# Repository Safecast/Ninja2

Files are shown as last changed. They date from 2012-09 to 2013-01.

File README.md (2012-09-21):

### Ninja2

Ninja2 is a board providing USB enabled atmega32u4 chip as the brain with an
802.15.4 radio for communication. It has a Li-Poly battery charger for juice
with a flexible booster that offers 3.3V to the microcontroller.

It can accomodate an OLED display from adafruit industries, a 13mm buzzer and a tactile switch for input.
http://www.adafruit.com/products/326

It was designed specifically for SAFECAST Japan as a complement to the bGeigie.

The board is cut to fit in Takachi box TW / TWN5-4-7.

The microcontroller will use the Arduino Leonardo bootloader and the Freaklabs chibiArduino 802.15.4 stack.

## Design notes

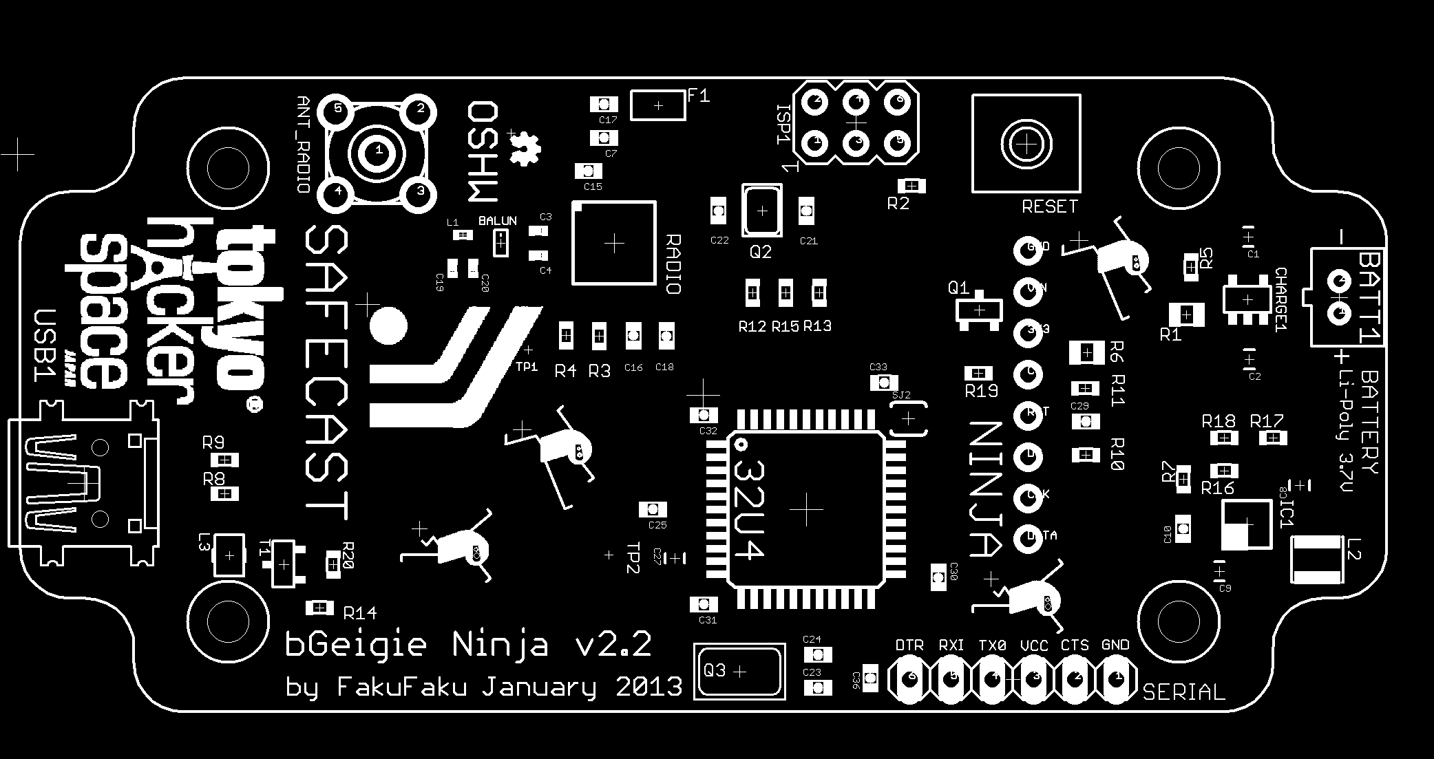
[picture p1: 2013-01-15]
Ninja2_brdtop.png

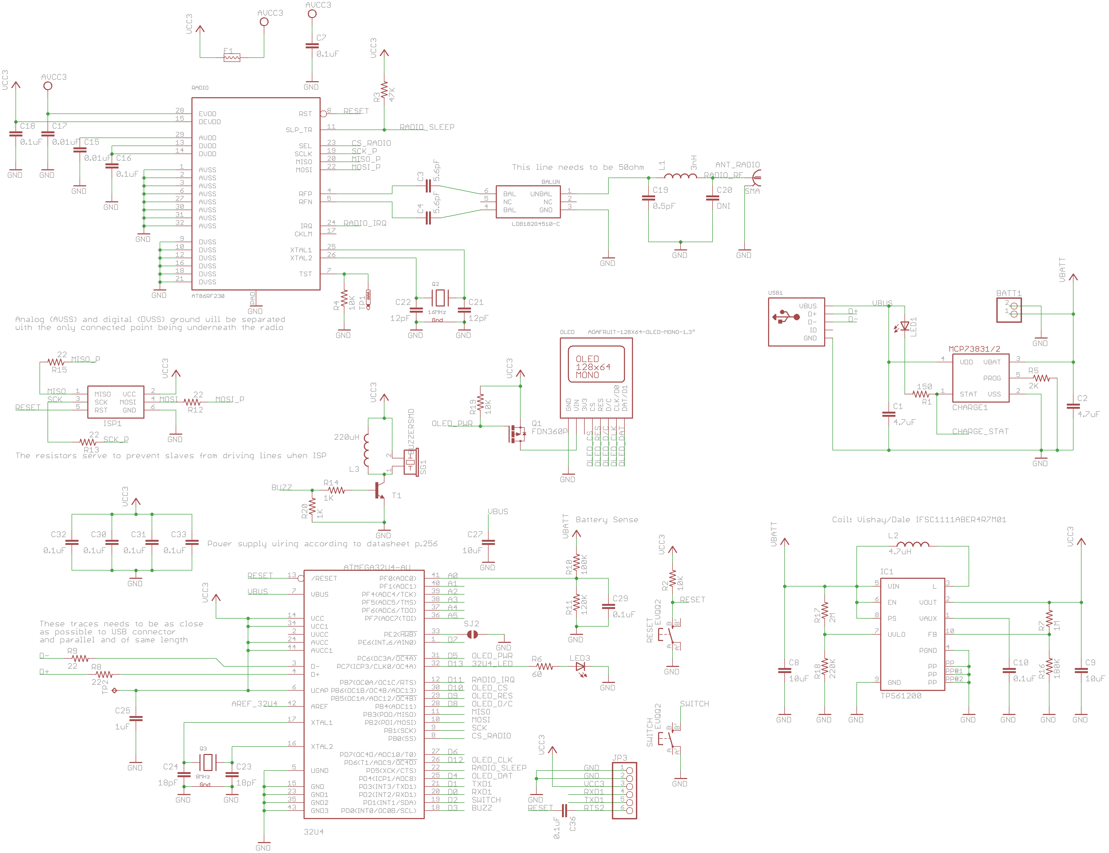
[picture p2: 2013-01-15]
Ninja2_sch.png

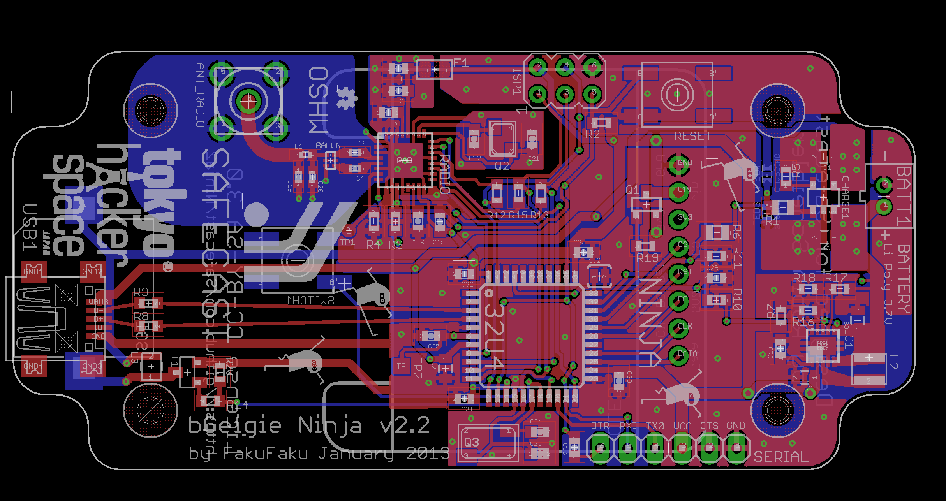
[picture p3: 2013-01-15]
Ninja2_brd.png

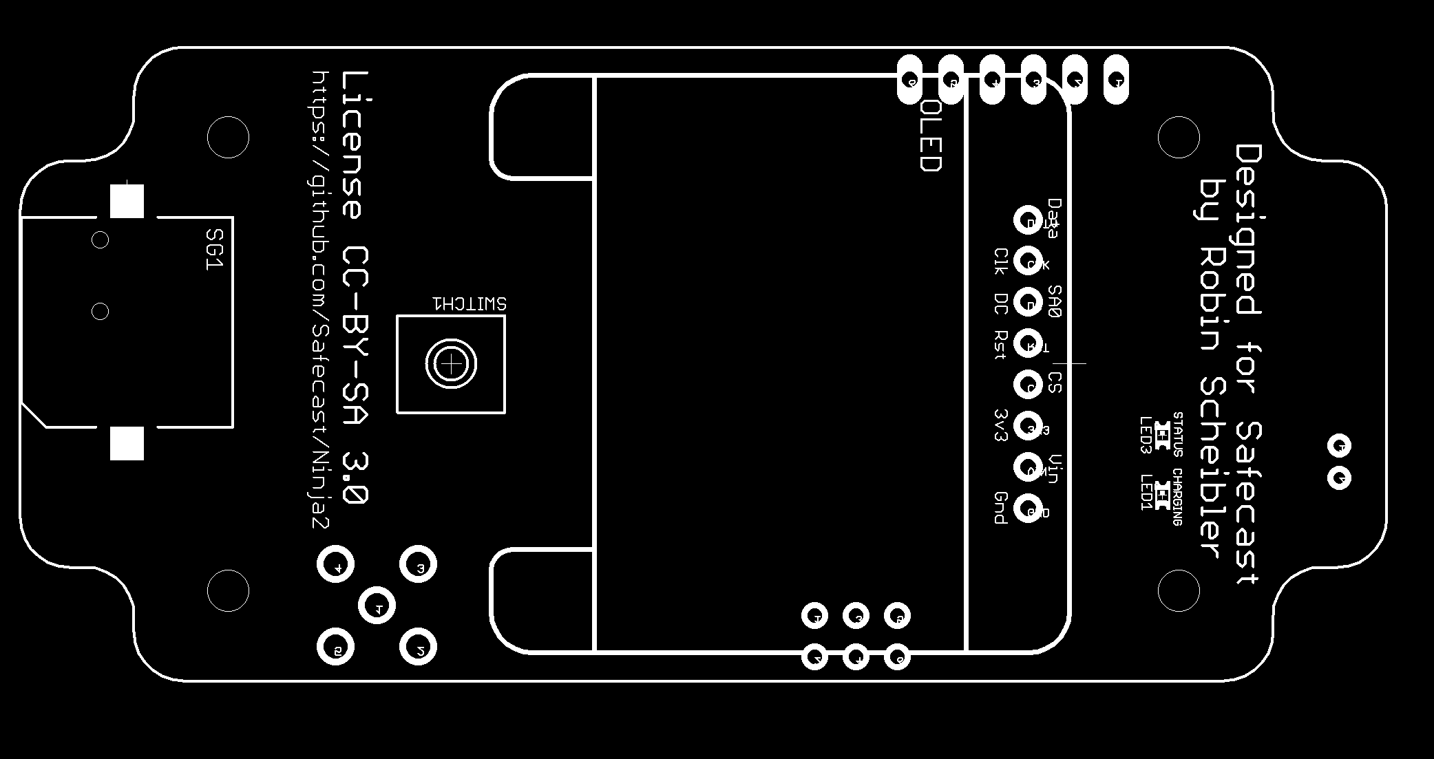
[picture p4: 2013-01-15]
Ninja2_brdbot.png

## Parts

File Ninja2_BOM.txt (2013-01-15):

Partlist

Exported from Ninja2.sch at 15.01.13 20:18

EAGLE Version 5.11.0 Copyright (c) 1988-2010 CadSoft

Part      Value                          Device                         Package                        Library          Sheet

32U4      ATMEGA32U4-AU                  ATMEGA32U4-AU                  TQFP44                         adafruit         1
ANT_RADIO SMA                            LTI-SASF54GT                   LTI-SASF54GT                   con-coax         1
BALUN     LDB182G4510-C                  LDB182G4510-C                  LDB182G4510-C                  Robin            1
BATT1                                    JST_2PIN-THM                   JST-PH-2-THM                   adafruit         1
C1        4.7uF                          CAP0805                        0805                           SparkFun         1
C2        4.7uF                          CAP0805                        0805                           SparkFun         1
C3        5.6pF                          CAP0402-CAP                    0402-CAP                       SparkFun         1
C4        5.6pF                          CAP0402-CAP                    0402-CAP                       SparkFun         1
C7        0.1uF                          CAP0603-CAP                    0603-CAP                       SparkFun         1
C8        10uF                           CAP0805                        0805                           SparkFun         1
C9        10uF                           CAP0805                        0805                           SparkFun         1
C10       0.1uF                          CAP0603-CAP                    0603-CAP                       SparkFun         1
C15       0.01uF                         CAP0603-CAP                    0603-CAP                       SparkFun         1
C16       0.1uF                          CAP0603-CAP                    0603-CAP                       SparkFun         1
C17       0.01uF                         CAP0603-CAP                    0603-CAP                       SparkFun         1
C18       0.1uF                          CAP0603-CAP                    0603-CAP                       SparkFun         1
C19       0.5pF                          CAP0402-CAP                    0402-CAP                       SparkFun         1
C20       DNI                            CAP0402-CAP                    0402-CAP                       SparkFun         1
C21       12pF                           CAP0603-CAP                    0603-CAP                       SparkFun         1
C22       12pF                           CAP0603-CAP                    0603-CAP                       SparkFun         1
C23       18pF                           CAP0603-CAP                    0603-CAP                       SparkFun         1
C24       18pF                           CAP0603-CAP                    0603-CAP                       SparkFun         1
C25       1uF                            CAP0603-CAP                    0603-CAP                       SparkFun         1
C27       10uF                           CAP0805                        0805                           SparkFun         1
C29       0.1uF                          CAP0603-CAP                    0603-CAP                       SparkFun         1
C30       0.1uF                          CAP0603-CAP                    0603-CAP                       SparkFun         1
C31       0.1uF                          CAP0603-CAP                    0603-CAP                       SparkFun         1
C32       0.1uF                          CAP0603-CAP                    0603-CAP                       SparkFun         1
C33       0.1uF                          CAP0603-CAP                    0603-CAP                       SparkFun         1
C36       0.1uF                          CAP0603-CAP                    0603-CAP                       SparkFun         1
CHARGE1   MCP73831/OT                    MCP73831/OT                    SOT23-5L                       adafruit         1
F1                                       L-FERRITE-BEAD-0805            0805                           Discreter        1
IC1       TPS61200                       TPS61200                       S-PDSO-N10                     texas            1
ISP1      AVRISP-6                       AVRISP-6                       AVRISP                         adafruit         1
JP3                                      PINHD-1X6                      1X06                           pinhead          1
L1        3nH                            INDUCTOR0402                   C0402                          SparkFun         1
L2        4.7uH                          INDUCTOR                       IFSC-1111AB-01                 Robin            1
L3        220uH                          INDUCTOR1007                   1007                           SparkFun         1
LED1                                     LEDCHIPLED_0603                CHIPLED_0603                   adafruit         1
LED3                                     LEDCHIPLED_0603                CHIPLED_0603                   adafruit         1
OLED      ADAFRUIT-128X64-OLED-MONO-1.3" ADAFRUIT-128X64-OLED-MONO-1.3" ADAFRUIT-128X64-OLED-MONO-1.3" Robin            1
Q1        FDN360P                        FDN360P                        SUPER-SOT3                     transistor-power 1
Q2        16MHz                          XTAL-4-3225                    NX3225                         adafruit         1
Q3        8MHz                           XTAL-4                         CRYSTAL-5032                   Robin            1
R1        150                            R-US_R0805                     R0805                          adafruit         1
R2        10K                            R-US_R0603                     R0603                          adafruit         1
R3        47K                            R-US_R0603                     R0603                          adafruit         1
R4        10K                            R-US_R0603                     R0603                          adafruit         1
R5        2K                             R-US_R0603                     R0603                          adafruit         1
R6        60                             R-US_R0805                     R0805                          adafruit         1
R7        1M                             R-US_R0603                     R0603                          adafruit         1
R8        22                             R-US_R0603                     R0603                          adafruit         1
R9        22                             R-US_R0603                     R0603                          adafruit         1
R10       100K                           R-US_R0603                     R0603                          adafruit         1
R11       120K                           R-US_R0603                     R0603                          adafruit         1
R12       22                             R-US_R0603                     R0603                          adafruit         1
R13       22                             R-US_R0603                     R0603                          adafruit         1
R14       1K                             R-US_R0603                     R0603                          adafruit         1
R15       22                             R-US_R0603                     R0603                          adafruit         1
R16       180K                           R-US_R0603                     R0603                          adafruit         1
R17       2M                             R-US_R0603                     R0603                          adafruit         1
R18       220K                           R-US_R0603                     R0603                          adafruit         1
R19       10K                            R-US_R0603                     R0603                          adafruit         1
R20       1K                             R-US_R0603                     R0603                          adafruit         1
RADIO     AT86RF230                      AT86RF230                      32QN1                          Robin            1
RESET     EVQQ2                          EVQQ2                          EVQ-Q2                         adafruit         1
SG1       BUZZERSMD                      BUZZERSMD                      KOBITONE-254-PB501-ROX         Robin            1
SJ2       SOLDERJUMPERTRACE              SOLDERJUMPERTRACE              SJ_2S-TRACE                    SparkFun         1
SWITCH    EVQQ2                          EVQQ2                          EVQ-Q2                         adafruit         1
T1                                       BC849-NPN-SOT23-BEC            SOT23-BEC                      transistor       1
TP1       PTR1B1,27                      PTR1B1,27                      B1,27                          testpad          1
TP2       TPTP15SQ                       TPTP15SQ                       TP15SQ                         testpad          1
USB1                                     USBMINIB                       USB-MINIB                      adafruit         1

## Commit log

2012-09-24 Changed buzzer to SMD type, much thinner.
    [Ninja2.brd, Ninja2.sch]
2012-10-29 Changed IRQ pin. Added buzzer driver circuit. Moved SPI pins. Added more explicit silkscreen labels. Updated all PNGs.
    [Ninja2.brd, Ninja2.sch]
2013-01-15 Modified board to fit in TW5-3-9. Use different coil (1007) for buzzer. Antenna now fits in box, do not stick out. v2.2.
    [Ninja2.brd, Ninja2.sch]
2013-01-15 Updated BOM.
